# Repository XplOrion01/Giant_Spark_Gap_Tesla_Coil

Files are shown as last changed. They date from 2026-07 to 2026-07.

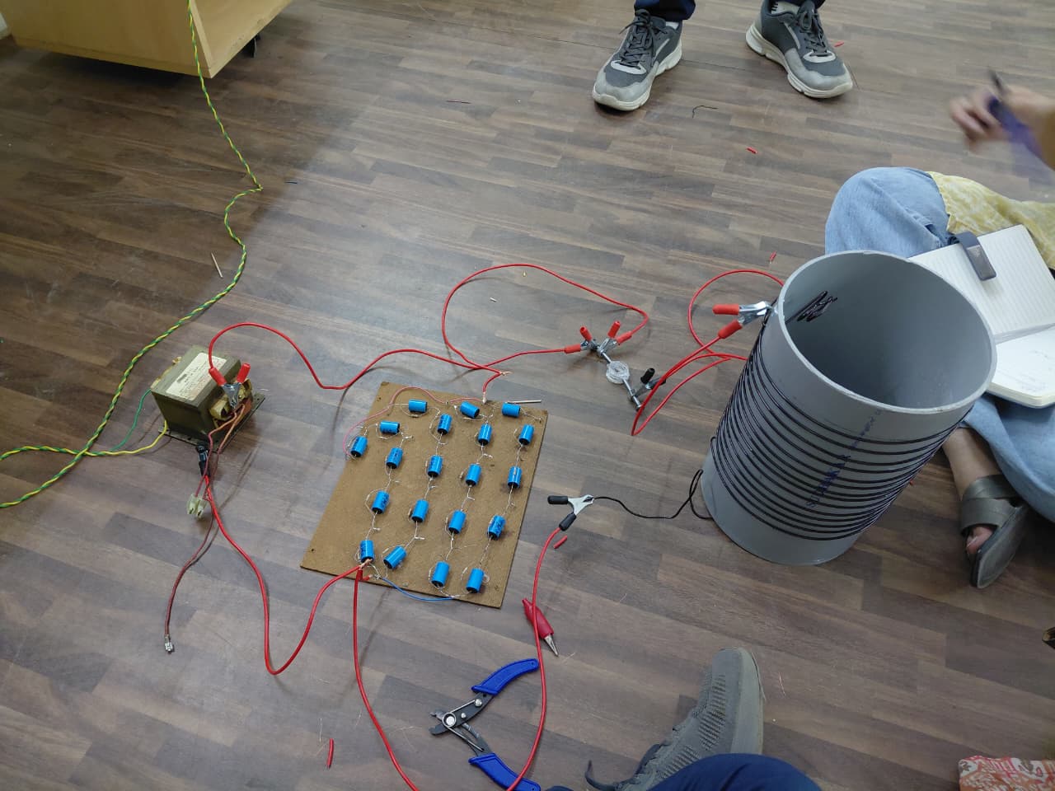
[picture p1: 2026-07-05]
Media/Primary Coil Testing.jpg

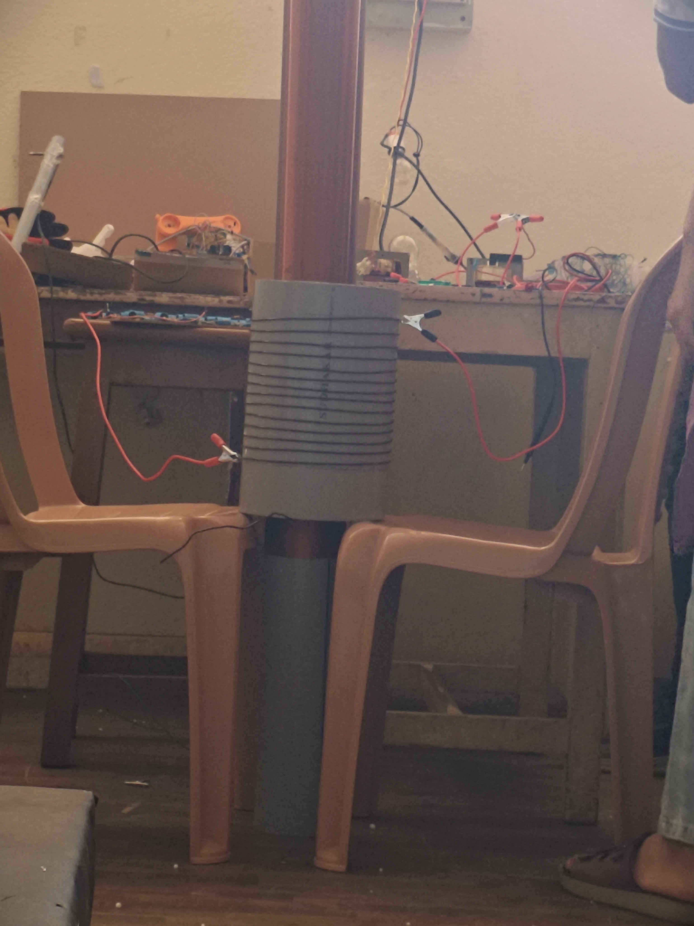
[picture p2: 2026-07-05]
Media/Uhh.jpg

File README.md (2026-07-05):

# Giant Spark Gap Tesla Coil (SGTC)

Welcome to the open-source repository for the **1400mm Giant Spark Gap Tesla Coil**. This project was researched, designed, and fabricated as a high-voltage exhibition model.

Final Demo

https://github.com/user-attachments/assets/93db6294-8219-484f-9322-babc6c6efc24

## Research & Development Team
This project was developed by a dedicated team of student engineers from the **Department of Electronics & Communication Engineering (ECE)**, University College of Engineering, **Osmania University**, Hyderabad, Telangana, India.

* **Occasion:** Built and demonstrated live for the department's prestigious national technical fest, **AAKRUTHI 2026**.
* **Timeline:** 10 days of rapid fabrication, 4 days of rigorous safety and resonance testing, followed by 2 days of continuous 24/7 deployment with zero failures.

---

## What is a Spark Gap Tesla Coil (SGTC)?
A Spark Gap Tesla Coil is the classic dual-resonant disruptive discharge circuit originally designed by Nikola Tesla. It relies on a high-voltage transformer to charge a primary capacitor bank until the voltage reaches the breakdown threshold of a physical air gap (the spark gap). 

When the air gap ionizes and fires, it forms a closed resonant circuit, transferring energy inductively from the heavy primary coil to the fine-wound secondary coil. Because the primary and secondary circuits are tuned to the exact same resonant frequency, the voltage multiplies exponentially via resonant transformer action, culminating in high-frequency, high-voltage streamers breaking out from the top load (toroid).

---

## System Architecture & Sub-Modules
The engineering documentation is modularly separated into the following core subsystems. You can explore the design blueprints, safety topologies, and calculations below:

* **[Part 1: Primary Circuit & Tank Components](./Primary_Circuit.md)** *Details on the 13 SWG helical primary inductor and the 10kV 37.6nF custom series-parallel capacitor bank network.*
* **[Part 2: High-Voltage Power Supply Network](./High-Voltage_Power_Supply_Network.md)** *Details on the dual-MOT 4400V AC step-up framework, overcurrent protection, and the four-bulb incandescent inductive/resistive ballast configuration.*
* **[Part 3: Secondary Coil & Toroid Layout](./Secondary_Circuit_and_Top-Load-(Toroid)_Assembly.md)** *Details on the 2500-turn 28 SWG secondary winding, the aluminum-encapsulated 200mm top-load sphere, and critical RF grounding requirements.*
* **[Part 4: Enclosure, Thermal Management & Operations](./EnclosureDesign_ThermalManagement_SystemOperation.md)** *Details on the custom wooden chassis, the 4-fan forced-air active ventilation loop, and dead-man switch safety protocols.*

---

## Design & Simulation Engineering
All primary engineering dimensions, primary-to-secondary mutual coupling coefficients, and resonant tuning values were verified using the industry-standard **JAVATC Tesla Coil Calculator**. 

---

## Critical Safety Warning & Disclaimer
High-voltage projects of this magnitude carry inherent lethal risks. 
* **Mains Isolation:** Always utilize a properly rated two-pole Miniature Circuit Breaker (MCB) and an easily accessible physical emergency stop.
* **RF Grounding:** **Never** operate the secondary coil without verifying a true, low-resistance Earth ground connection. Inadequate grounding will cause immediate high-voltage feedback into the electrical grid.
* **Fire Safety:** Due to extreme thermal loads on the spark gap and ballast system, **always maintain a dedicated fire extinguisher** in the testing perimeter.
* **Ozone & Ventilation:** Ensure the operating environment has active air circulation to disperse ozone and nitrous oxide gases generated by the spark gap arc.

---

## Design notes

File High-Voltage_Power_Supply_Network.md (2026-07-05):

High-Voltage Power Supply Network

I. Power Architecture and Safety Constraints

i.The system utilizes a standard domestic input (230 V AC, 50 Hz) and steps it up to the kilovolt (kV) range required to energize the resonant tank circuit.

ii.Voltage Limitations: While optimal spark gap Tesla coils typically utilize 10-20 kV power supplies, this system was intentionally limited to approximately 4.4 kV to satisfy university laboratory safety regulations and mitigate extreme arc-over risks during presentation.

II. Component Specifications

i.High-Voltage Transformers: The power stage consists of two identical Microwave Oven Transformers (MOTs). Each individual transformer steps up the input voltage from 220 V to a secondary output of 2200 V AC.

ii.Ballasting / Current Limiting: MOTs are shunted transformers designed to run at high currents and will rapidly overheat or trip mains breakers if unrestricted. To limit the input draw and stabilize the arc, an inductive/resistive ballast network consisting of four 100 W incandescent filament bulbs connected in parallel was placed inline with the supply.

iii.Overcurrent & System Protection: For primary safety, a dedicated Two-Pole Miniature Circuit Breaker (MCB) is integrated at the main AC input line. The two-pole MCB is critical as it completely isolates both the Live and Neutral lines simultaneously in the event of a fault.

III. Wiring Topology and Circuit Configuration

The primary power supply section is wired according to the following electrical configuration:

i.Current Limiter Network: Four 100 W bulbs are wired in parallel with each other to increase the total allowable current throughput while still providing a safety ceiling.

ii.Transformer Interconnection: Low-Voltage (Primary) Side: The primary inputs of the two MOTs are wired in parallel to receive the incoming 230 V AC supply.
High-Voltage (Secondary) Side: The high-voltage secondary outputs of the two MOTs are wired in series (ensuring proper phasing) to combine their outputs, resulting in a total supply voltage of 4400 V AC (4.4 KV).

iii.Mains Control Loop: The AC mains input feeds directly into the two-pole MCB. The output of the MCB is wired in series with the parallel bulb ballast network, 
which then connects in series to the parallel primary inputs of the MOT assembly.

The combined high-voltage series output from the MOT secondaries is then routed directly to the primary tank circuit.

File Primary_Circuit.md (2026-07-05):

Primary Circuit & Components

I. Circuit Topology and Configuration

The primary circuit utilizes a dual Microwave Oven Transformer (MOT) configuration supplying a high-voltage output of 4400 V AC. The circuit topology is arranged as follows:

   i. The high-voltage AC output 4.4 KV is connected in parallel with the resonant tank capacitor bank.
  
  ii. The spark gap and the primary coil are connected in series with one another.
  
 iii. This series combination (spark gap + primary coil) is then connected in parallel across the primary high-voltage terminals.

Detailed circuit diagrams and physical assembly photographs can be found in the Images/ directory of this repository.

II. Primary Coil Specifications

The primary coil was constructed as a vertical helical inductor using the following parameters:
  
  i. Conductor: 13 SWG (Standard Wire Gauge) enameled copper wire.
 
 ii. Form/Support: A 110 mm diameter, 400 mm tall PVC pipe acting as the structural chassis.

iii. Windings: Approximately 14 turns, evenly spaced across the form factor.
 
 iv. Total Material Used: Approximately 5 meters of 13 SWG wire.

III. Spark Gap Assembly & Thermal Management

The spark gap acts as the high-speed switching element that periodically discharges the tank circuit.

  i. Design: A static two-electrode configuration mounted on an insulating wooden base to prevent electrical arcing to the chassis and minimize heat transfer.

 ii. Electrodes: While copper electrodes are recommended for optimal conductivity and lifespan, steel nails were utilized for this build, spaced at an 
     experimental gap of approximately 3 mm (adjustable between 2-5 mm).

iii. Thermal Considerations: The electrodes experience rapid thermal loading during operation. If the electrodes overheat, the air in the gap remains ionized,
     preventing the coil from firing correctly until it cools. To mitigate this thermal runaway, a dedicated forced-air cooling fan was integrated directly
     adjacent to the gap to accelerate cooling cycles.

IV. Resonant Tank Capacitor Bank
    To determine the required primary capacitance, calculations were conducted using the JAVATC Tesla Coil Calculator. Due to component availability and high-  
    voltage safety margins, a custom capacitor bank was engineered:
    Individual Unit Rating: 2 kV, 47 nF film capacitors.

Bank Configuration: A series-parallel network consisting of 4 parallel strings, where each string contains 5 capacitors connected in series (a 5*4 array, totaling 20 individual capacitors).

Final Equivalent Bank Rating: 10 kV maximum voltage rating with a total capacitance of 37.6 nF}.

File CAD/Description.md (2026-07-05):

This was the final cad file submitted for inspection by us to the Department Head for approval

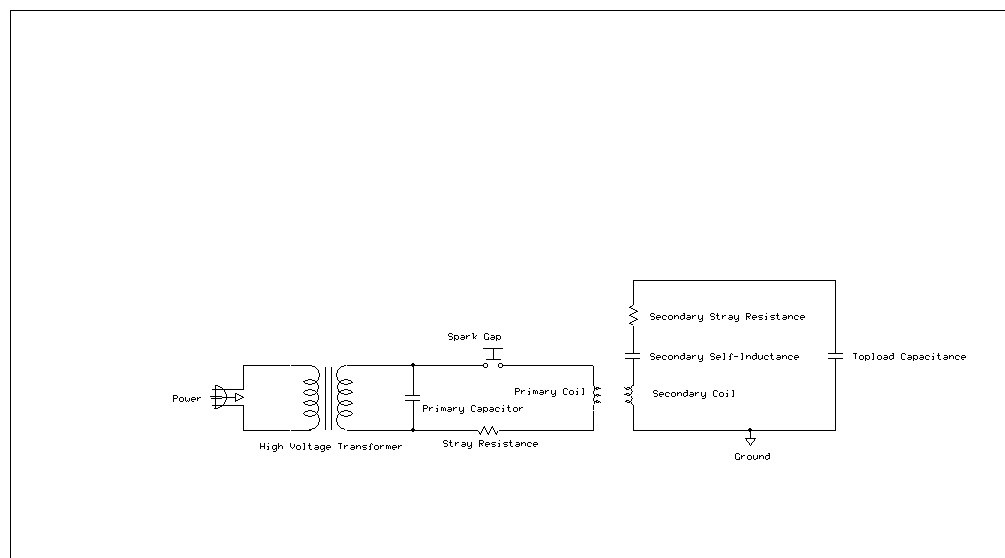
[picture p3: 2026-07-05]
Media/Schematic.jpg

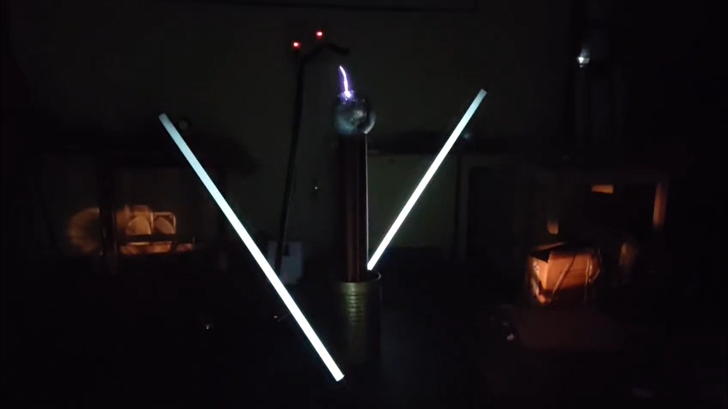
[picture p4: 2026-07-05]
Media/Final Demo.png

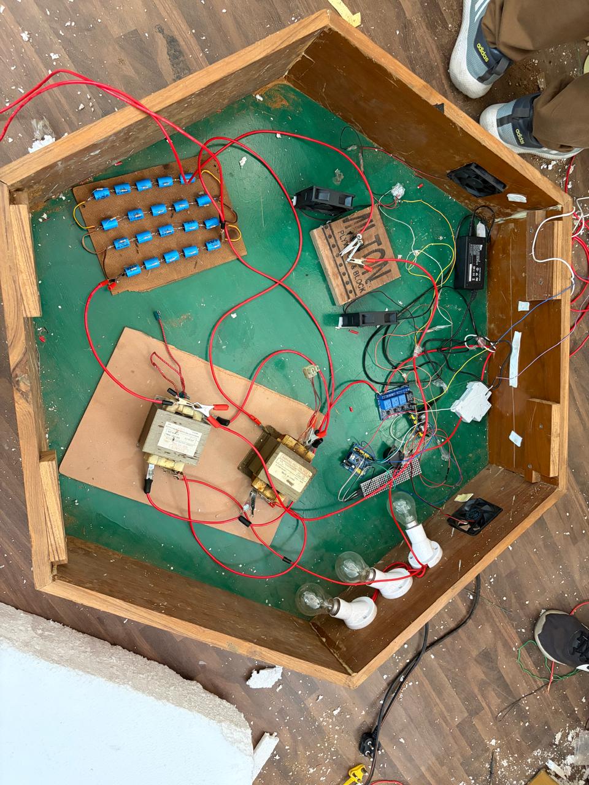
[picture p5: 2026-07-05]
Media/Internal Circuit Placement.jpg

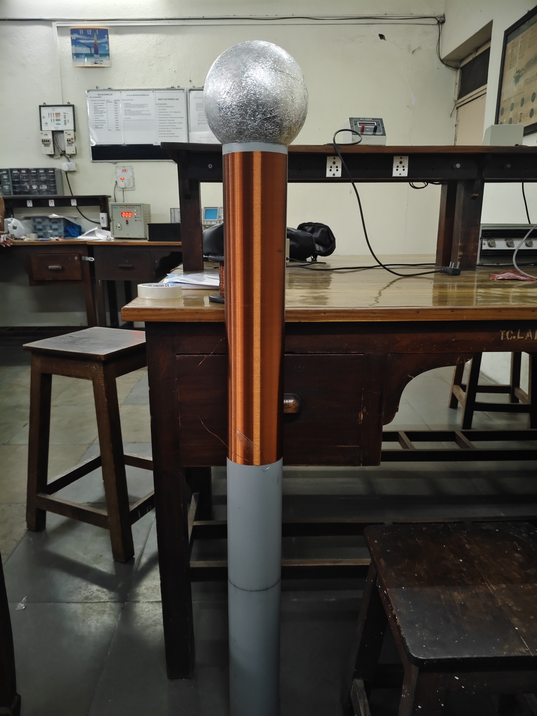
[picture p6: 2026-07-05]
Media/Secondary Coil.jpg

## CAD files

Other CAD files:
CAD/Tesla coil design.f3d

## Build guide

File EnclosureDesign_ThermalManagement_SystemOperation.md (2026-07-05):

Enclosure Design, Thermal Management, and System Operation

I. Structural Chassis and Enclosure Design

Because this system was engineered as a university exhibition model, both structural aesthetics and functional component isolation were key design priorities.

i. Chassis Material: A custom wooden shell enclosure was fabricated to house the high-voltage control electronics and primary circuitry safely out of view.

ii. Coil Integration and Alignment: The top of the wooden enclosure features a precision-cut mounting hole.

iii. The un-wound 200 mm base of the secondary PVC coil form inserts directly into this hole, securing the heavy vertical structure without external bracing.

iv. The primary helical coil sits directly on top of the enclosure surface, perfectly concentric with the secondary coil, ensuring correct electromagnetic coupling geometry at the base.

v. Internal Component Layout: The high-voltage MOT network, resonant tank capacitor bank, and spark gap assembly are securely mounted within the lower interior compartment of the wooden chassis.

II. Forced-Air Cooling and Ventilation System

Operating high-power components within a closed wooden shell introduces severe thermal risks. A dedicated active cooling network was integrated to manage thermal dissipation:

i. Fan Network: Four independent 12 V DC cooling fans are mounted directly into ventilated ports carved into the chassis walls.

ii. Targeted Cooling: Strategic placement routes airflow directly over the incandescent bulb ballast network (which generates significant resistive heat) and across the static spark gap (to prevent thermal electrode degradation and continuous air ionization). The remaining fans establish a continuous intake/exhaust loop for the inner chamber.

iii. Auxiliary Power Supply: The fans are energized via a dedicated 12 V DC power adapter. The AC input of this adapter is wired in parallel directly to the load side of the main MCB, ensuring the cooling system activates immediately when the system is main-powered.

III. Control Interface and Operational Procedure

To ensure maximum safety during public demonstration, the control interface separates system power from the high-voltage firing sequence via a dead-man style configuration:

i. The Firing Control Switch: A momentary push-button switch is wired in series on the 230 V AC line, positioned immediately prior to the bulb ballast network. The high-voltage primary circuit will only energize while this button is actively held down by the operator.

ii. Independent Cooling Behavior: Because the $12\text{ V}$ cooling adapter is wired directly to the MCB, the cooling fans run continuously regardless of whether the push button is pressed. This allows the fans to cool down the internal components even between active firing windows.

Standard Operating Protocol:

System Initialization: Engaging the primary Two-Pole MCB powers on the internal cooling fan array and prepares the system.

Activation Sequence: Pressing and holding the momentary push switch completes the primary circuit loop, initiating the spark gap arc and generating the high-frequency secondary discharge.

Deactivation Sequence: Releasing the push switch immediately terminates the high-voltage output. Toggling the MCB to the "OFF" position isolates the entire apparatus from the mains grid.

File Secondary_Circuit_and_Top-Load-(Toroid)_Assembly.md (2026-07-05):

Secondary Circuit and Top Load (Toroid) Assembly

I. Secondary Coil Physical Specifications

The secondary coil is a high-Q resonant inductor engineered to provide maximum voltage magnification via resonant transformer action.

i. Coil Form: A 1200 mm tall, 80 mm diameter non-conductive PVC pipe.

ii. Winding Length: The enameled wire is precision-wound along $1000\text{ mm}$ (1 meter) of the pipe. The remaining $200\text{ mm}$ at the bottom serves 
as an un-wound structural base that inserts into the main chassis/stand.

iii. Conductor & Turn Count: Wound using 28 SWG (Standard Wire Gauge) enameled copper wire. The coil features approximately 2,500 continuous turns.

iv. Material Quantity: Approximately $630\text{ meters}$ of 28 SWG wire was utilized (from a $700\text{ meter}$ spool).

II. Top Load (Toroid) Design

The top load acts as a capacitor to store energy before it discharges as a spark, and its smooth profile prevents premature breakout.

i. Geometry: A spherical geometry was utilized, constructed from a $200\text{ mm}$ diameter plastic core.

ii. Conductive Layer: The core is completely encapsulated in two layers of heavy-duty aluminum foil to create a smooth, highly conductive surface area.

iii. Placement: The sphere is securely mounted directly atop the secondary PVC coil form.

III. Electrical Interconnections and Grounding Network

Proper grounding is the most critical safety and functional aspect of the secondary circuit. The connections are arranged as follows:

i. High-Potential Termination: The top terminal of the 28 SWG secondary winding is electrically bonded directly to the aluminum foil of the top load.

ii. Low-Potential (Ground) Termination: The base terminal of the secondary winding is routed to a dedicated RF ground. For this setup, it is connected to 
    the building's electrical grounding system via the earth pin of a standard domestic mains socket.

 CRITICAL SAFETY WARNING: The secondary circuit requires a highly reliable, low-resistance earth 
 ground to function properly and safely. Before operation, the mains socket earth connection must be rigorously verified using a multimeter or socket tester. 
 A weak or broken ground will prevent the coil from firing and can cause high-voltage feedback into household appliances or the primary circuit.

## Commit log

2026-07-05 Add primary circuit documentation
    Documented the primary circuit topology, coil specifications, spark gap assembly, and resonant tank capacitor bank details.
2026-07-05 Add documentation for High-Voltage Power Supply Network
    Document the power architecture, component specifications, and wiring topology for the high-voltage power supply network.
2026-07-05 Refactor Primary Circuit documentation for clarity
    Corrected formatting and redundancy issues in the Primary Circuit documentation. Ensured consistent presentation of circuit topology, primary coil specifications, spark gap assembly, and resonant tank capacitor bank details.
2026-07-05 Update High-Voltage Power Supply Network documentation
    Clarified wiring topology and circuit configuration details, including the Mains Control Loop and safety features.
2026-07-05 Update assembly instructions for secondary circuit and topload
    Reformatted sections for clarity and added emphasis on safety warnings.
2026-07-05 Add documentation for enclosure design and operation
    Document details the design and operational procedures for the enclosure, thermal management, and control interface of the system.
2026-07-05 Add final CAD file description for approval
2026-07-05 Fusion CAD file
    [Tesla coil design.f3d]
2026-07-05 Rename High-Voltage Power Supply Network.md to High-Voltage_Power_Supply _Network.md
2026-07-05 Rename High-Voltage_Power_Supply _Network.md to High-Voltage_Power_Supply_Network.md
2026-07-05 Rename Primary Circuit.md to Primary_Circuit.md
2026-07-05 Rename Secondary Circuit and Top Load (Toroid) Assembly.md to Secondary_Circuit_and_Top-Load-(Toroid)_Assembly.md
